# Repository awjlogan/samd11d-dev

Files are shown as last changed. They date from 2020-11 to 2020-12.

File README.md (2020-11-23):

# SAMD1x-DEV

A minimal breakout board for the [Microchip (Atmel) ATSAMD11D][atsamd11] Cortex-M0+ based microcontroller. All pins are broken out to standard 2.54 mm (0.1 in) headers.

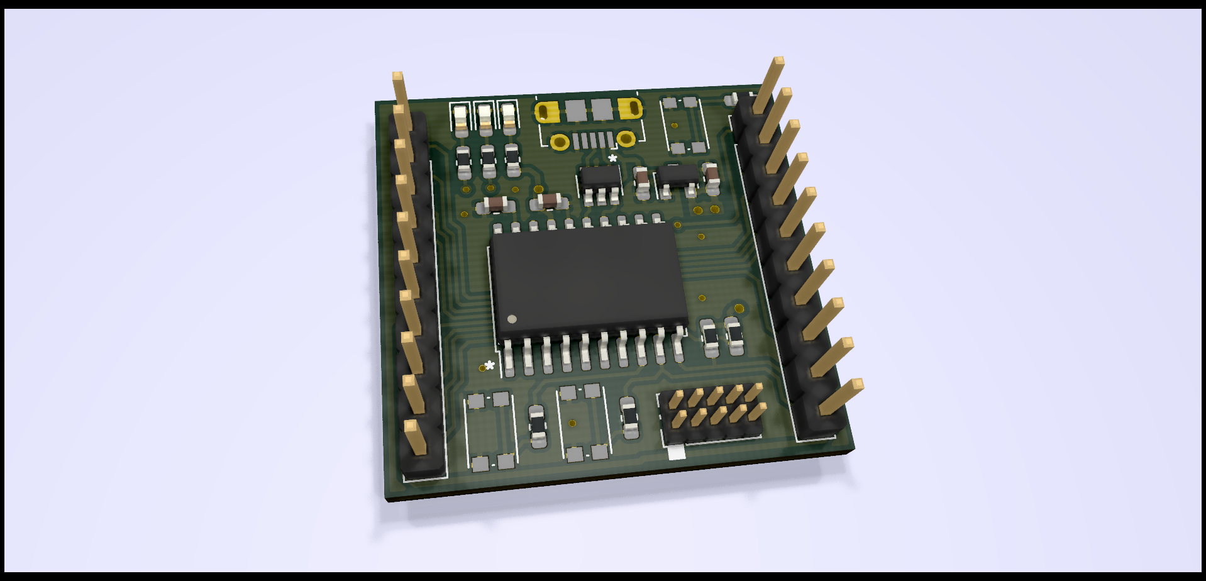
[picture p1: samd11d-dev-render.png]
Rendered image


All design files and source code are under the [_Don't Be A Dick_][dbad-github] license.

## Hardware

PCBs were designed with KiCad 5; all files are provided and no custom KiCad parts are required. Most components are surface mount, with all passives being 0603 sized. Note that due to the part density, there are no reference designators on the top silkscreen.

A full bill of materials with order codes for Farnell and Mouser is included.

## Change Notes

### v0.1 -> v0.21

 - [X] Use USB-B with mounting pegs rather than pure SMD.
 - [X] Add graphical notch on programming header space.
 - [X] Choose a more widely available button (C&K KMR2).
 - [X] Increase LED limiting resistor values.
 - [X] Move LEDs off PA02 and PA04 as these are useful for ADC/DAC, now on PA14/15.
 - [X] Remove LED on PA03, just have ADC reference decoupling.
 - [X] Add power indication LED on 3V3.
 - [X] Move switch onto pin with fewer alt functions (PA16).
 - [X] Add additional switch (PA22).

[atsamd11]: https://www.microchip.com/wwwproducts/en/ATSAMD11D14
[dbad-github]: https://github.com/philsturgeon/dbad

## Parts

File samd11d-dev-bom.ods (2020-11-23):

Refs | Component | Package | Value | Unit | Quantity | Notes | Optional | Manufacturer | Manufacturer code | Farnell | Mouser
C3, C4 | Capacitor | 0603 | 4.7 | uF | 2 | >= 6.3 V | No | Generic |  | 3013436 | 963-JMK107BB7475KA-T
C5, C6 | Capacitor | 0603 | 100 | nF | 2 | >= 6.3 V | C5: No. C6: Yes | Generic |  | 2581044 | 710-885012206020
D1, D2, D3 | LED | 0603 |  |  | 3 | Vf <= 3 V | Yes | Generic |  | 3265380 | 710-150060RS55040
J1 | 10 pin header |  |  |  | 1 | 1.27 mm pitch, 2x5 | No | Generic |  | 1577743 | 200-MTMS10502TD002
J2 | USB Micro-B |  |  |  | 1 |  | No | Wuerth | 629105150521 | 2470822 | 710-629105150521
R1, R2 | Resistor | 0603 | 4.7 | kR | 2 | I2C pull ups | Yes | Generic |  | 2694880 | 755-SFR03EZPF4701
R3-R6 | Resistor | 0603 | 330 | R | 6 | Current limiting | No | Generic |  | 2447339 | 603-RC0603JR-07330RL
SW1, SW2, SW3 | Switch |  |  |  | 3 |  | Yes | C&K Components | KMR2232G | 2845730 | 688-SKRKAEE020
U1 | SAMD11D14A | SOIC-20 |  |  | 1 |  | No | Microchip | ATSAMD11D14A-SSUT | 2475666 | 556-ATSAMD11D14ASSUT
U3 | MCP1700T-33 | SOT-23 |  |  | 1 |  | No | Microchip | MCP1700T-3302E/TT | 1296592 | 579-MCP1700T3302E/TT
U4 | USBLC6-2SC6 | SOT-23-5 |  |  | 1 | ESD protection | Yes | STMicroelectronics | USBLC6-2SC6 | 1269406 | 511-USBLC6-2SC6

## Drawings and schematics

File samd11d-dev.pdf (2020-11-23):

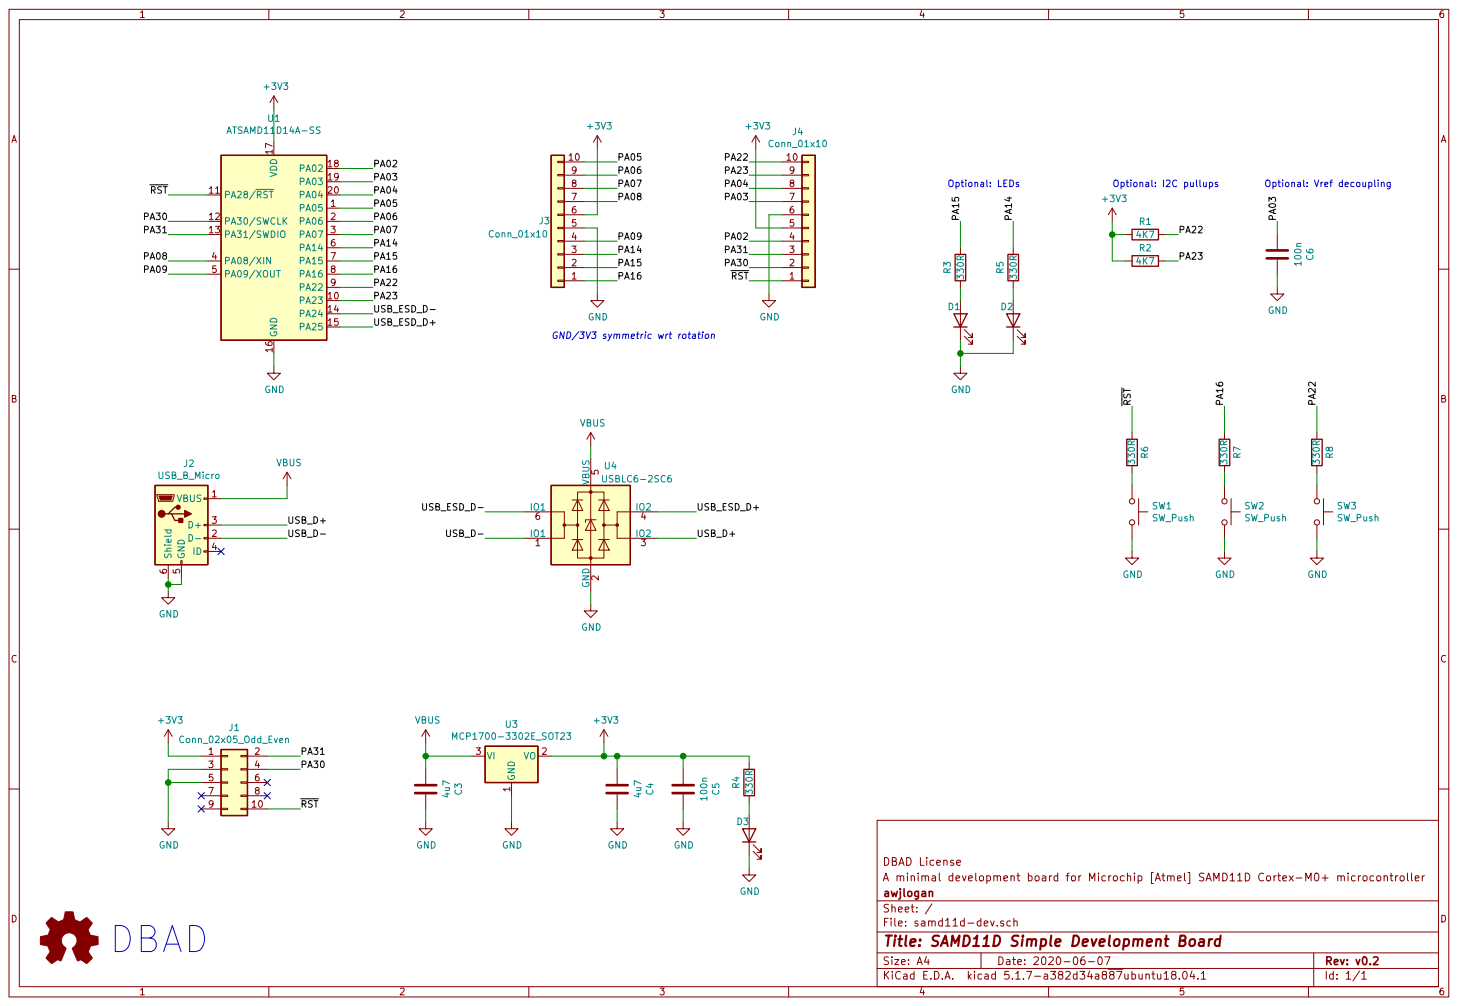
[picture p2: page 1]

A minimal development board for Microchip [Atmel] SAMD11D Cortex-M0+ microcontroller DBAD License

File: samd11d-dev.sch Sheet: / awjlogan

Id: 1/1 Title: SAMD11D Simple Development Board

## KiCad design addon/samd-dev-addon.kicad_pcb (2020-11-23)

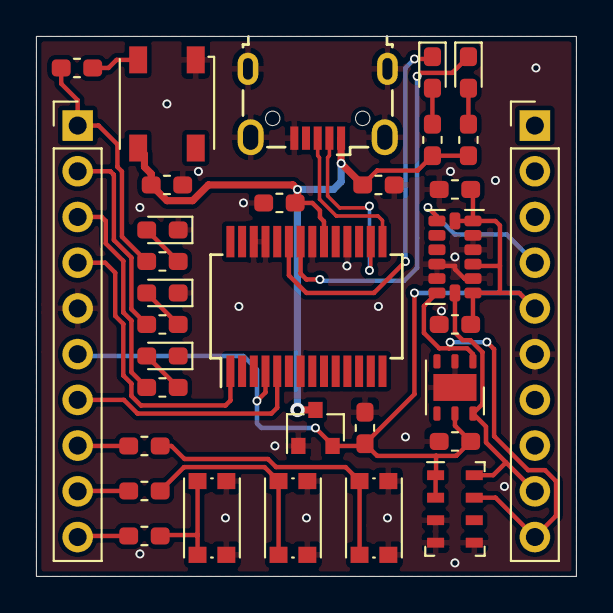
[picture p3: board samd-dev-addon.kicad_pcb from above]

Board: 2 copper layers, 30.0 x 30.0 mm, 33 parts (0 on the bottom side), 27 nets.

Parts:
C1, C2: 2u2; C_0603_1608Metric_Pad1.05x0.95mm_HandSolder
C3, C4, C5, C6, C7: 100n; C_0603_1608Metric_Pad1.05x0.95mm_HandSolder
D1, D2, D4, D5, D6: LED; LED_0603_1608Metric_Pad1.05x0.95mm_HandSolder
D3: Inolux_IN-PI554FCH; LED_Inolux_IN-PI554FCH_PLCC4_5.0x5.0mm_P3.2mm
J1: USB_B_Micro; USB_Micro-B_Wuerth_629105150521
J2, J3: Conn_01x10; PinHeader_1x10_P2.54mm_Vertical
R1, R2, R3, R4, R5, R6, R7, R8, R9: 330R; R_0603_1608Metric_Pad1.05x0.95mm_HandSolder
SW1, SW2, SW3: SW_Push; SW_Push_1P1T_NO_CK_KMR2
U1: MCP1700-3302E_SOT23; SOT-23
U2: FT232RL; SSOP-28_5.3x10.2mm_P0.65mm
U3: Si7020-A20; DFN-6-1EP_3x3mm_P1mm_EP1.5x2.4mm
U4: ADXL343; LGA-14_3x5mm_P0.8mm_LayoutBorder1x6y
U5: MS5607-02BA; LGA-8_3x5mm_P1.25mm

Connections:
+3V3: C2.1, C3.1, C4.1, C6.1, J2.6, J3.5, U1.2, U2.4, U3.5, U4.1, U4.3, U4.6, U4.7, U5.1, U5.2
+5V: C1.1, C5.1, C7.1, D3.3, J1.1, R1.1, R2.1, U1.3, U2.20
/D+: J1.3, U2.15
/D-: J1.2, U2.16
/PA02: J3.4, U4.8
/PA05: J2.10, R3.2
/PA06: J2.9, R4.2
/PA07: J2.8, R5.2
/PA08: J2.7, U2.5
/PA09: J2.4, U2.1
/PA14: J2.3, R7.2
/PA15: J2.2, R8.2
/PA16: J2.1, R6.1, R9.2
/PA22: J3.10, U3.1, U4.13, U5.7
/PA23: J3.9, U3.6, U4.14, U5.8
/RXLED: D2.1, U2.22
/TXLED: D1.1, U2.23
GND: C1.2, C2.2, C3.2, C4.2, C5.2, C6.2, C7.2, D3.1, D4.1, D5.1, D6.1, J1.5, J1.6, J2.5, J3.6, SW1.2, SW2.2, SW3.2, U1.1, U2.7, U2.18, U2.21, U2.25, U2.26, U3.2, U3.7, U4.2, U4.4, U4.5, U4.11, U4.12, U5.3, U5.4, U5.5
unnamed: D1.2, R1.2
unnamed: D2.2, R2.2
unnamed: D3.2, R6.2
unnamed: D4.2, R7.1
unnamed: D5.2, R8.1
unnamed: D6.2, R9.1
unnamed: R3.1, SW1.1
unnamed: R4.1, SW2.1
unnamed: R5.1, SW3.1

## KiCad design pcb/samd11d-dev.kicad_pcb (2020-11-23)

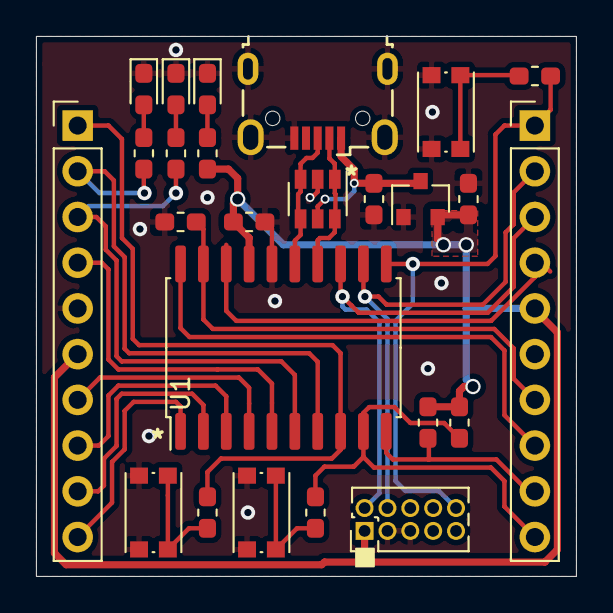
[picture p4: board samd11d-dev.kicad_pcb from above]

Board: 2 copper layers, 30.0 x 30.0 mm, 25 parts (0 on the bottom side), 27 nets.

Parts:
C3, C4: 4u7; C_0603_1608Metric_Pad1.05x0.95mm_HandSolder
C5, C6: 100n; C_0603_1608Metric_Pad1.05x0.95mm_HandSolder
D1, D2, D3: LED; LED_0603_1608Metric_Pad1.05x0.95mm_HandSolder
J1: Conn_02x05_Odd_Even; PinHeader_2x05_P1.27mm_Vertical
J2: USB_B_Micro; USB_Micro-B_Wuerth_629105150521
J3, J4: Conn_01x10; PinHeader_1x10_P2.54mm_Vertical
R1, R2: 4K7; R_0603_1608Metric_Pad1.05x0.95mm_HandSolder
R3, R4, R5, R6, R7, R8: 330R; R_0603_1608Metric_Pad1.05x0.95mm_HandSolder
SW1, SW2, SW3: SW_Push; SW_Push_1P1T_NO_CK_KMR2
U1: ATSAMD11D14A-SS; SOIC-20W_7.5x12.8mm_P1.27mm
U3: MCP1700-3302E_SOT23; SOT-23
U4: USBLC6-2SC6; SOT-23-6

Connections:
+3V3: C4.2, C5.2, J1.1, J3.6, J4.5, R1.2, R2.2, R4.1, U1.17, U3.2
/PA02: J4.4, U1.18
/PA03: C6.2, J4.7, U1.19
/PA04: J4.8, U1.20
/PA05: J3.10, U1.1
/PA06: J3.9, U1.2
/PA07: J3.8, U1.3
/PA08: J3.7, U1.4
/PA09: J3.4, U1.5
/PA14: J3.3, R5.1, U1.6
/PA15: J3.2, R3.1, U1.7
/PA16: J3.1, R7.2, U1.8
/PA22: J4.10, R1.1, R8.2, U1.9
/PA23: J4.9, R2.1, U1.10
/PA30: J1.4, J4.2, U1.12
/PA31: J1.2, J4.3, U1.13
/USB_D+: J2.3, U1.15, U4.3, U4.4
/USB_D-: J2.2, U1.14, U4.1, U4.6
/~RST: J1.10, J4.1, R6.2, U1.11
GND: C3.1, C4.1, C5.1, C6.1, D1.1, D2.1, D3.1, J1.3, J1.5, J2.5, J2.6, J3.5, J4.6, SW1.2, SW2.2, SW3.2, U1.16, U3.1, U4.2
unnamed: D1.2, R3.2
unnamed: D2.2, R5.2
unnamed: D3.2, R4.2
unnamed: R6.1, SW1.1
unnamed: R7.1, SW2.1
unnamed: R8.1, SW3.1
VBUS: C3.2, J2.1, U3.3, U4.5

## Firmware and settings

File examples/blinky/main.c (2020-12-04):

/*
 * Copyright (c) 2020, Angus Logan <awjlogan@gmail.com>
                 2016, Alex Taradov <alex@taradov.com>
 * All rights reserved.
 *
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
 * THIS SOFTWARE IS PROVIDED BY THE COPYRIGHT HOLDERS AND CONTRIBUTORS "AS IS"
 * AND ANY EXPRESS OR IMPLIED WARRANTIES, INCLUDING, BUT NOT LIMITED TO, THE
 * IMPLIED WARRANTIES OF MERCHANTABILITY AND FITNESS FOR A PARTICULAR PURPOSE
 * ARE DISCLAIMED. IN NO EVENT SHALL THE COPYRIGHT HOLDER OR CONTRIBUTORS BE
 * LIABLE FOR ANY DIRECT, INDIRECT, INCIDENTAL, SPECIAL, EXEMPLARY, OR
 * CONSEQUENTIAL DAMAGES (INCLUDING, BUT NOT LIMITED TO, PROCUREMENT OF
 * SUBSTITUTE GOODS OR SERVICES; LOSS OF USE, DATA, OR PROFITS; OR BUSINESS
 * INTERRUPTION) HOWEVER CAUSED AND ON ANY THEORY OF LIABILITY, WHETHER IN
 * CONTRACT, STRICT LIABILITY, OR TORT (INCLUDING NEGLIGENCE OR OTHERWISE)
 * ARISING IN ANY WAY OUT OF THE USE OF THIS SOFTWARE, EVEN IF ADVISED OF THE
 * POSSIBILITY OF SUCH DAMAGE.
 */

//-----------------------------------------------------------------------------
#include <stdlib.h>
#include <stdint.h>
#include <stdbool.h>
#include <string.h>

#include "samd11.h"
#include "hal_gpio.h"
#include "samd-dev.h"


//-----------------------------------------------------------------------------
#define PERIOD_FAST     100
#define PERIOD_SLOW     500

HAL_GPIO_PIN(LED0,     A, 14)
HAL_GPIO_PIN(LED1,     A, 15)
HAL_GPIO_PIN(BUTTON,   A, 16)
HAL_GPIO_PIN(UART_TX,  A, 8)
HAL_GPIO_PIN(UART_RX,  A, 9)


//-----------------------------------------------------------------------------
static void timer_set_period(uint16_t i)
{
    TC1->COUNT16.CC[0].reg = (F_CPU / 1000ul / 256) * i;
    TC1->COUNT16.COUNT.reg = 0;
}


//-----------------------------------------------------------------------------
void irq_handler_tc1(void)
{
    if (TC1->COUNT16.INTFLAG.reg & TC_INTFLAG_MC(1)) {
        HAL_GPIO_LED0_toggle();
        TC1->COUNT16.INTFLAG.reg = TC_INTFLAG_MC(1);
    }
}


//-----------------------------------------------------------------------------
static void timer_init(void)
{
    PM->APBCMASK.reg |= PM_APBCMASK_TC1;

    /* Setup clock system */
    GCLK_CLKCTRL_Type clkctrl = {
        .bit.ID = TC1_GCLK_ID,  /* Generic clock selection ID */
        .bit.GEN = 0,           /* Generic clock generator */
        .bit.CLKEN = true,      /* Clock enable */
        .bit.WRTLOCK = false    /* Write lock */
    };
    GCLK->CLKCTRL.reg = clkctrl.reg;

    /* Setup TC1 */
    TC_CTRLA_Type ctrla = {
        .bit.SWRST = false,                             /* Software reset */
        .bit.ENABLE = false,                            /* Enable */
        .bit.MODE = TC_CTRLA_MODE_COUNT16_Val,          /* TC mode */
        .bit.WAVEGEN = TC_CTRLA_WAVEGEN_MFRQ_Val,       /* Waveform generation operation */
        .bit.PRESCALER = TC_CTRLA_PRESCALER_DIV256_Val, /* Prescalar */
        .bit.RUNSTDBY = false,                          /* Run in standby */
        .bit.PRESCSYNC = TC_CTRLA_PRESCSYNC_RESYNC_Val  /* Prescalar/counter synchronisation */
    };
    TC1->COUNT16.CTRLA.reg = ctrla.reg;

    /* Set period, and start timer */
    TC1->COUNT16.COUNT.reg = 0;
    timer_set_period(PERIOD_SLOW);
    TC1->COUNT16.CTRLA.reg |= TC_CTRLA_ENABLE;

    /* Enable interrupt */
    TC1->COUNT16.INTENSET.reg = TC_INTENSET_MC(1);
    NVIC_EnableIRQ(TC1_IRQn);
}


//-----------------------------------------------------------------------------
static void uart_init(uint32_t baud)
{
    uint64_t br = (uint64_t)65536 * (F_CPU - 16 * baud) / F_CPU;

    HAL_GPIO_UART_TX_out();
    HAL_GPIO_UART_TX_pmuxen(PORT_PMUX_PMUXE_D_Val); // SERCOM-ALT
    HAL_GPIO_UART_RX_in();
    HAL_GPIO_UART_RX_pmuxen(PORT_PMUX_PMUXE_D_Val); // SERCOM-ALT

    PM->APBCMASK.reg |= PM_APBCMASK_SERCOM0;

    GCLK_CLKCTRL_Type clkctrl = {
        .bit.ID = SERCOM0_GCLK_ID_CORE, /* Generic clock selection ID */
        .bit.GEN = 0,                   /* Generic clock generator */
        .bit.CLKEN = true,              /* Clock enable */
        .bit.WRTLOCK = false            /* Write lock */
    };
    GCLK->CLKCTRL.reg = clkctrl.reg;

    SERCOM_USART_CTRLA_Type ctrla = {
        .bit.SWRST = false,                                     /* Software reset */
        .bit.ENABLE = false,                                    /* Enable */
        .bit.MODE = SERCOM_USART_CTRLA_MODE_USART_INT_CLK_Val,  /* Operating mode */
        .bit.RUNSTDBY = false,                                  /* Run during standby */
        .bit.IBON = false,                                      /* Immediate buffer overflow notification */
        .bit.SAMPR = 0,                                         /* Sample */
        .bit.TXPO = 0,                                          /* TX pinout (0) */
        .bit.RXPO = 2,                                          /* RX pinout (2) */
        .bit.SAMPA = 0,                                         /* Sample adjustment */
        .bit.FORM = 0,                                          /* Frame format (USART frame) */
        .bit.CMODE = 0,                                         /* Communication mode */
        .bit.CPOL = 0,                                          /* Clock polarity */
        .bit.DORD = 1                                           /* Data order (LSB first) */
    };
    SERCOM0->USART.CTRLA.reg = ctrla.reg;

    SERCOM_USART_CTRLB_Type ctrlb = {
        .bit.CHSIZE = 0,                                        /* Character size (8) */
        .bit.SBMODE = 0,                                        /* Stop bit mode */
        .bit.COLDEN = false,                                    /* Collision detection enable */
        .bit.SFDE = false,                                      /* Start of frame detection enable */
        .bit.ENC = false,                                       /* IR Encoding */
        .bit.PMODE = 0,                                         /* Parity mode (even) */
        .bit.TXEN = true,                                       /* TX enable */
        .bit.RXEN = true                                        /* RX enable */
    };
    SERCOM0->USART.CTRLB.reg = ctrlb.reg;

    SERCOM0->USART.BAUD.reg = (uint16_t)br+1;
    SERCOM0->USART.CTRLA.reg |= SERCOM_USART_CTRLA_ENABLE;
}


//-----------------------------------------------------------------------------
int main(void) {

    uint32_t cnt = 0;
    uint32_t total_chars = 0;
    bool fast = false;

    sys_init();
    timer_init();
    uart_init(115200);

    HAL_GPIO_LED0_out();
    HAL_GPIO_LED0_clr();
    HAL_GPIO_LED1_out();
    HAL_GPIO_LED1_clr();

    HAL_GPIO_LED0_write(0x1U);

    /* 128bits of unique ID -> 32 hex characters + NULL */
    uint32_t unique_id[4];
    char unique_id_str[33];

    /* Get unique ID (Section 9.6)
     * Unfortunately, it's not contiguous so just enter address
     */
    unique_id[0] = *(volatile uint32_t *) 0x0080A00Cu;
    unique_id[1] = *(volatile uint32_t *) 0x0080A040u;
    unique_id[2] = *(volatile uint32_t *) 0x0080A044u;
    unique_id[3] = *(volatile uint32_t *) 0x0080A048u;

    /* Convert the unique ID into hex characters */
    for (uint8_t i = 0; i < 4; i++) {
        for (uint8_t j = 0; j < 8; j++) {
            uint8_t nibble;
            nibble = (unique_id[i] & (0xF << j * 4)) >> (j * 4);
            unique_id_str[7 - j + i * 8] = "0123456789abcdef"[nibble];
        }
    }
    unique_id_str[32] = (char) 0;

    uart_puts("\r\nHello! I am SAMD 0x");
    uart_puts(unique_id_str);
    uart_puts("\r\n");

    HAL_GPIO_LED1_write(0x1U);

    while (1) {
        cnt++;
        if (cnt == 5000) {
            cnt = 0;
            timer_set_period(fast ? PERIOD_SLOW : PERIOD_FAST);
            fast = !fast;
            __WFI();

            /* Print up to 64 . */
            if (total_chars++ < 64) {
                uart_putc('.');
            }
        }
    }

   return 0;
}

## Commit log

2020-02-19 First public release
    [bom.ods, samd11d-dev.kicad_pcb, samd11d-dev.sch]
2020-02-19 Add pcb folder
    [bom.ods, samd11d-dev.kicad_pcb, samd11d-dev.sch]
2020-06-07 Version 0.2 changes. Include schematic PDF and PNG of rendered board
    [bom.ods, samd11d-dev-bom.ods, samd11d-dev.kicad_pcb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]
2020-06-07 Wrong bracket type
2020-11-06 Complete new layout for v0.21
    [samd11d-dev.kicad_pcb, samd11d-dev.sch]
2020-11-10 Sensor add on board commit
    [samd-dev-addon.kicad_pcb, samd-dev-addon.sch]
2020-11-23 v2.1 manufactured
    [samd-dev-addon.kicad_pcb, samd-dev-addon.sch, samd11d-dev-bom.ods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]
2020-12-04 Light up LEDs
2020-12-13 Add blinking LED example
